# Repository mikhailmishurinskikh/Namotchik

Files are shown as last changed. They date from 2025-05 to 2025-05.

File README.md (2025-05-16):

# Намотчик

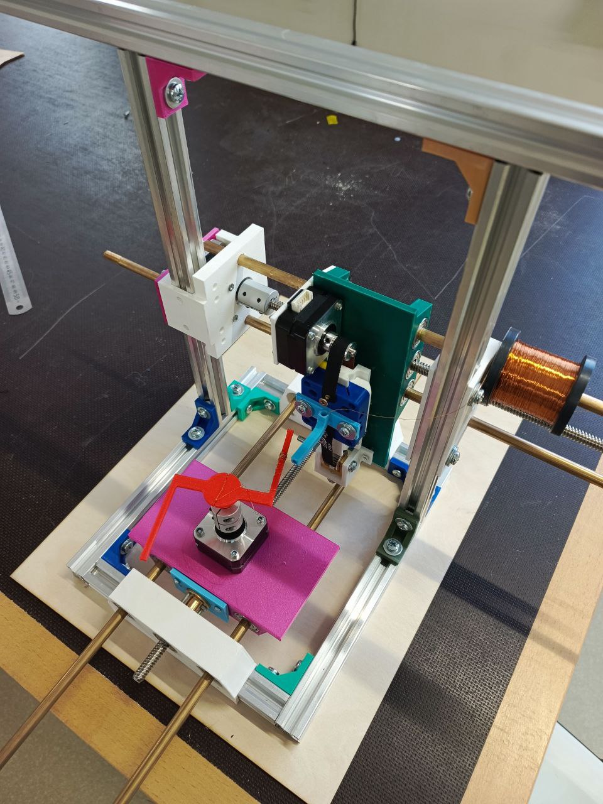
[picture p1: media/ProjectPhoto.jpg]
Фото устройства

Видео демонстрации работы приведено в Видео

## Команда
1. **Мишуринских Михаил**  
   - Email: mishurinskikh.mn@phystech.edu  
   - Telegram: [@mis246](https://t.me/mis246)  
   - Роль: проектирование деталей, сборка  

2. **Новосёлов Ярослав**  
   - Email: novoselov.iav@phystech.edu  
   - Роль: написание управляющей программы, проектирование деталей  

## Причины выбора проекта
Большие возможности для практического применения проекта, его универсальность.

## Достигнутая цель
Создано устройство для автоматической намотки проволоки на звукосниматели и другие объекты

## Задачи
1. Проектирование необходимых деталей: 
   - Угловые соединители алюминиевых профилей
   - Держатели для ходовых винтов
   - Вертикальная и горизонтальная платформы
   - Устройство для натяжения ремня
   - Держатели для двигателей
   - Рельса для вертикального движения прицеливающего устройства
2. Сборка корпуса из напечатанных деталей, алюминиевых профилей
3. Установка платформ, организация их движения при помощи ходового винта
4. Создание коробки для электроники
5. Написание управляющей программы
6. Настройка и тестирование устройства

## Описание устройства
Устройство напоминает по устройству 3D-принтер: оно состоит из прицеливающего устройства, которое способно перемещаться по трём осям над объектом (катушкой или звукоснимателем) и наматывать на него проволоку. 

**Конструкция:**
- Корпус состоит из двух рамок: вертикальной и горизонтальной.
- Над горизонтальной рамкой находится платформа с шаговым двигателем, закрепленная с применением ходового винта (перемещается по горизонтальной оси).
- Вертикальная платформа закреплена на другом ходовом винте и перемещается по оси, перпендикулярной нижней платформе.
- На платформе расположен электродвигатель, перемещающий ремень с кареткой и прицеливающим устройством.
- Для натяжения ремня используется специальное приспособление.

**Принцип работы:**  
Конструкция позволяет прицеливающему устройству вращаться вокруг объекта (закрепленного на двигателе) и наматывать на него проволоку.

## Описание процесса решения задач
1. **Создание корпуса:**
   - Напечатаны держатели для ходового винта (`three`, `three_up` в репозитории).
   - Напечатаны угловые соединители (`angle`), собран корпус из алюминиевых профилей.
2. **Установка платформ:**
   - Напечатаны платформы (`plate`, `plate_up`), держатель для двигателя (`holder`).
   - Установлены на корпус с использованием ходового винта и латунных балок.
3. **Система с ремнем:**
   - Напечатаны рельса (`rail`), каретка (`carriage`), натягивающее устройство (`fixskiv`, `fixfixskiv`).
   - Закреплен ремень, достигнуто перемещение каретки при вращении двигателя.
4. **Электроника:**
   - Создана коробка для электроники.
5. **Программирование:**
   - Написан код для движения каретки (лежит в репозитории).
6. **Тестирование:**
   - Напечатан образец звездочки для намотки.
   - Создана тестовая программа для демонстрации работы.

## Существующие аналоги и альтернативы
1. [Видео с подобной системой перемещения каретки](https://youtu.be/BMVNzjB5hds?si=kCWIetpFhRKtm2jW)
2. [Видео с похожей конструкцией](https://youtu.be/jD39MupZx00?si=GmyoavpNxICr1N5V)
3. [Статья с другим дизайном намотчика](https://3dtoday.ru/blogs/alkutepov/kak-ya-sobiral-namotocnyi-stanok-dlya-namotki-katusek-zvukosnimatelei)

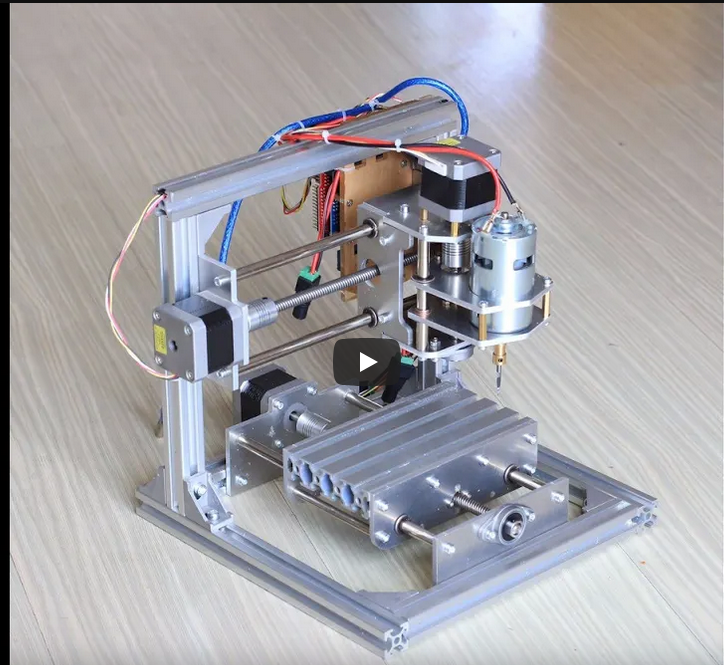
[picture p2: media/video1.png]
Похожая конструкция
  
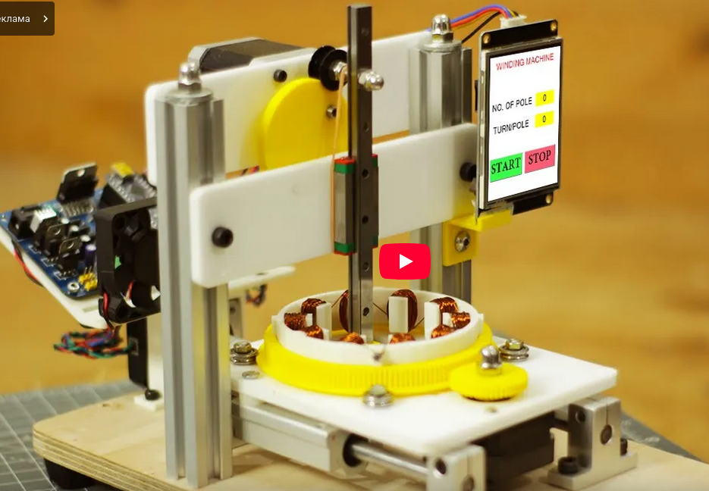
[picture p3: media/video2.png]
Основной аналог
  

### Отличия проекта от аналогов:
- Использование системы с ремнем для вертикального перемещения каретки (высокая скорость).
- Возможность легкого переконструирования под конкретные задачи.
- Намотка с внешней стороны звездочки (в аналогах — с внутренней).

### Недостатки и доработки:
- Требуется подбор параметров намотки.
- Необходима панель управления.
- Улучшение внешнего вида.

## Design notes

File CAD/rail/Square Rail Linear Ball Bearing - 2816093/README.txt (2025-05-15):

Square Rail Linear Ball Bearing by 3DPRINTINGWORLD on Thingiverse: https://www.thingiverse.com/thing:2816093

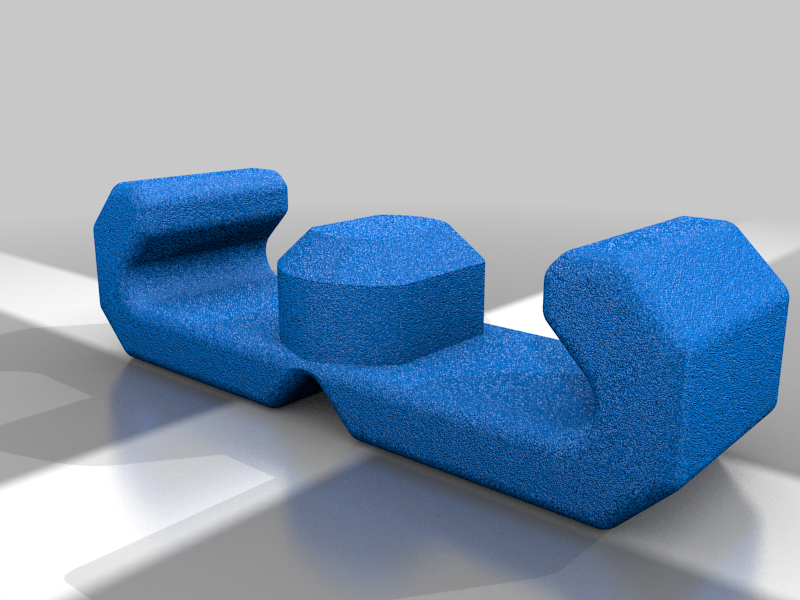
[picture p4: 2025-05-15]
CAD/rail/Square Rail Linear Ball Bearing - 2816093/images/674540b3cc713451a258298c891a3b4f.png

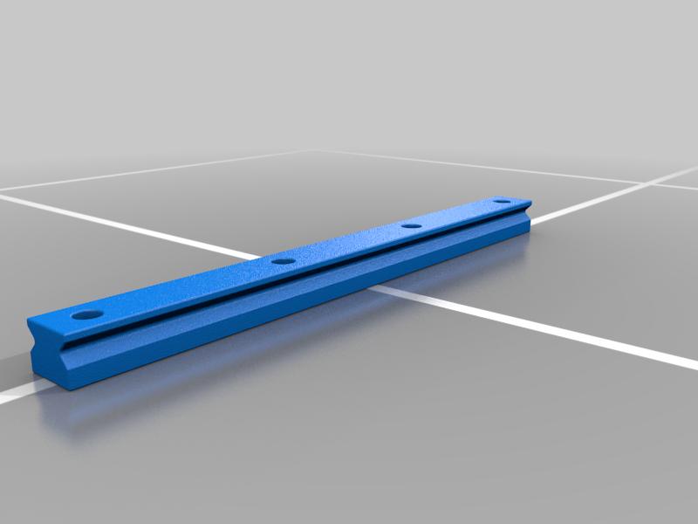
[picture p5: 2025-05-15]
CAD/rail/Square Rail Linear Ball Bearing - 2816093/images/a7a430d8cf4bb123bb5e223ab3fe0eaa.png

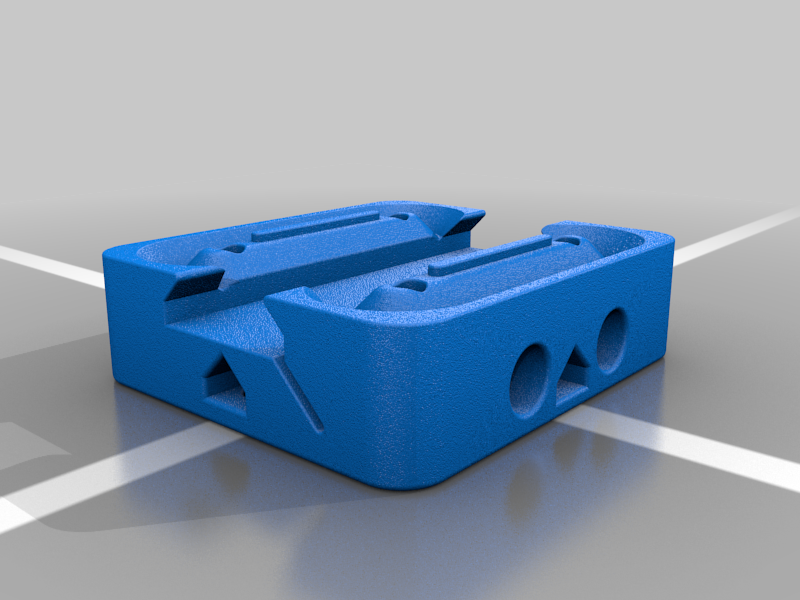
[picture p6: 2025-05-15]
CAD/rail/Square Rail Linear Ball Bearing - 2816093/images/061dc79fe75d56e6988cc07eb85009e7.png

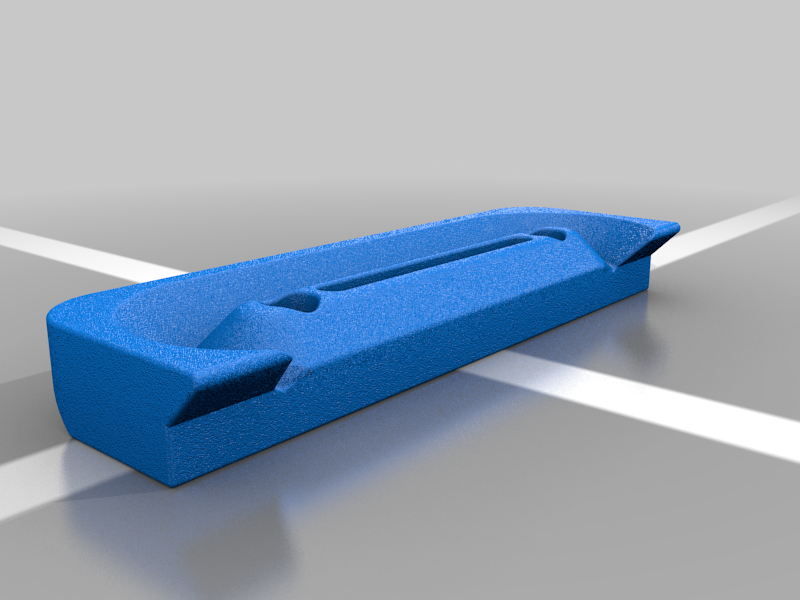
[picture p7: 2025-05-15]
CAD/rail/Square Rail Linear Ball Bearing - 2816093/images/fa1c53716b4c98238ab20a3283d675de.png

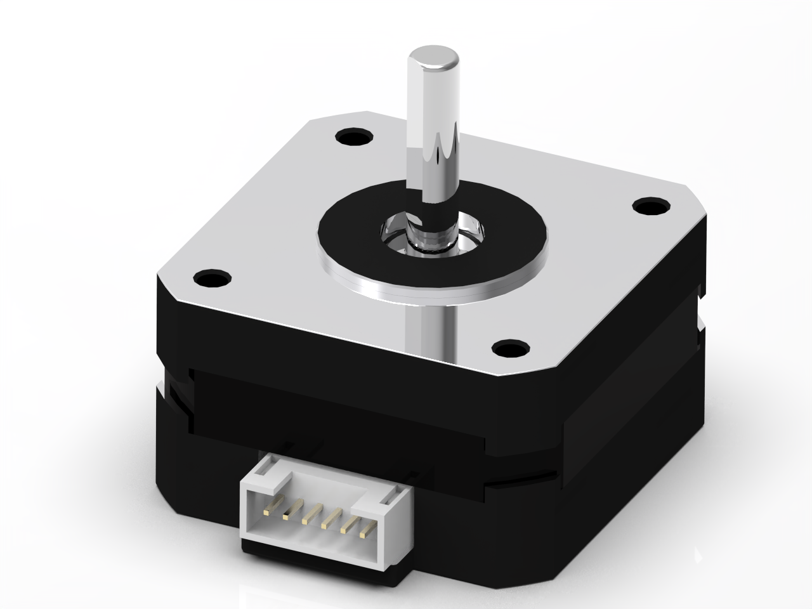
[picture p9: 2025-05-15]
CAD/nemasmall/nema-17-pancake-17hs4023-1.snapshot.6/sdasda.2.png

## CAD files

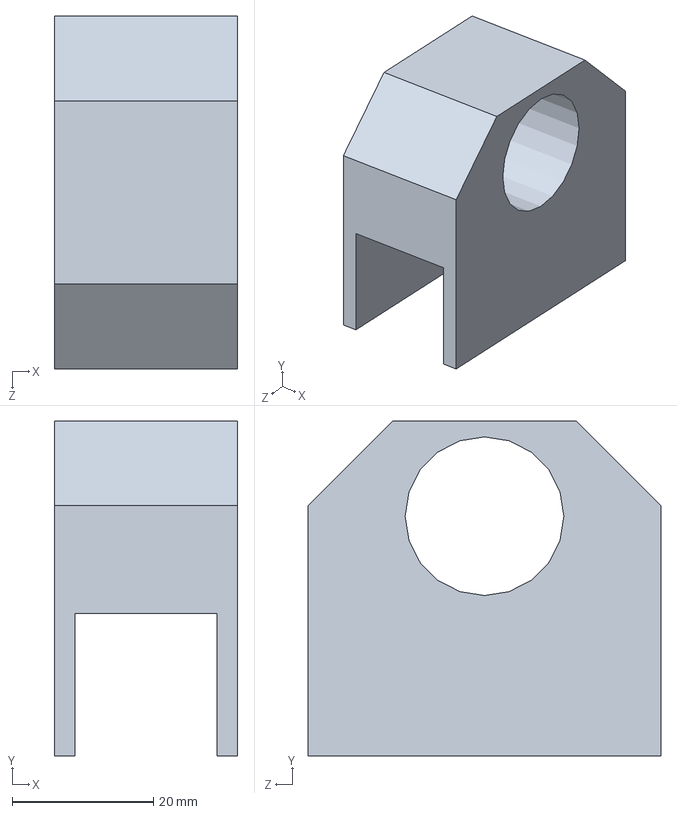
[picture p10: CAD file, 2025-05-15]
CAD/mainBearingDown.SLDPRT
26.0 x 47.5 x 50.0 mm

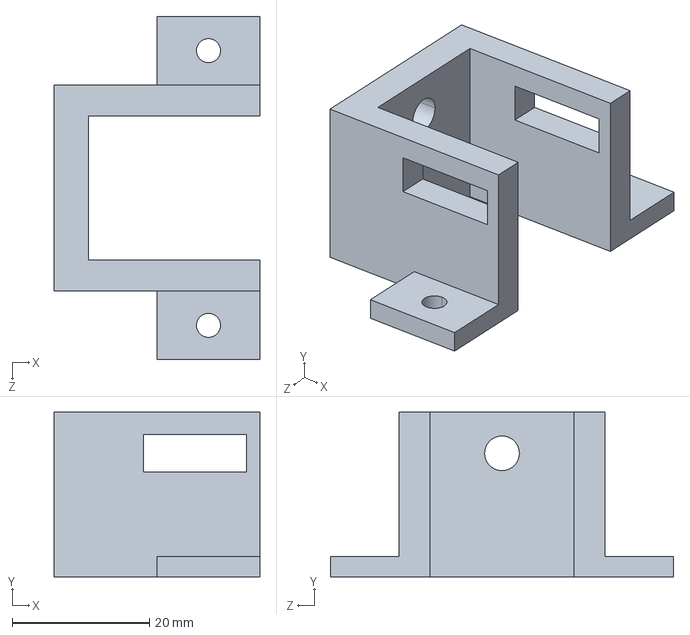
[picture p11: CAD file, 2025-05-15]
CAD/fixfixskiv.STEP
30.0 x 24.0 x 50.0 mm

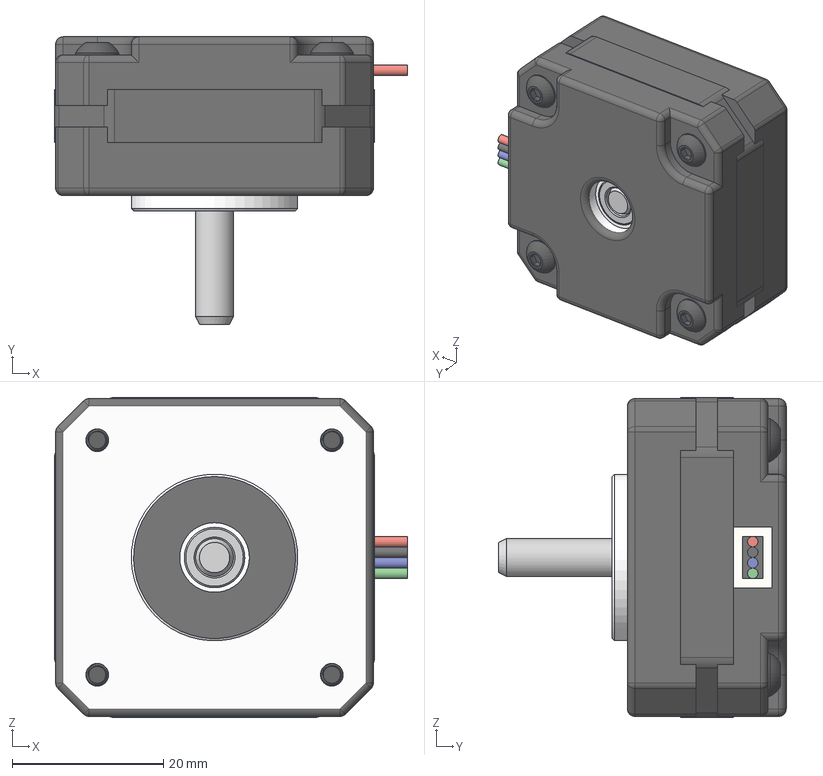
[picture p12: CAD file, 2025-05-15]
CAD/nemasmall/17hm08-1204s-nema17-pancake-21mm-1.snapshot.2/17HM08-1204S Nema17 Pancake 21mm.step
46.7 x 38.0 x 42.3 mm
M3 - 12mm 92095A183 x 4
Front body
Back body
Middle body
Bearings
Shaft
Wire guard
Wires

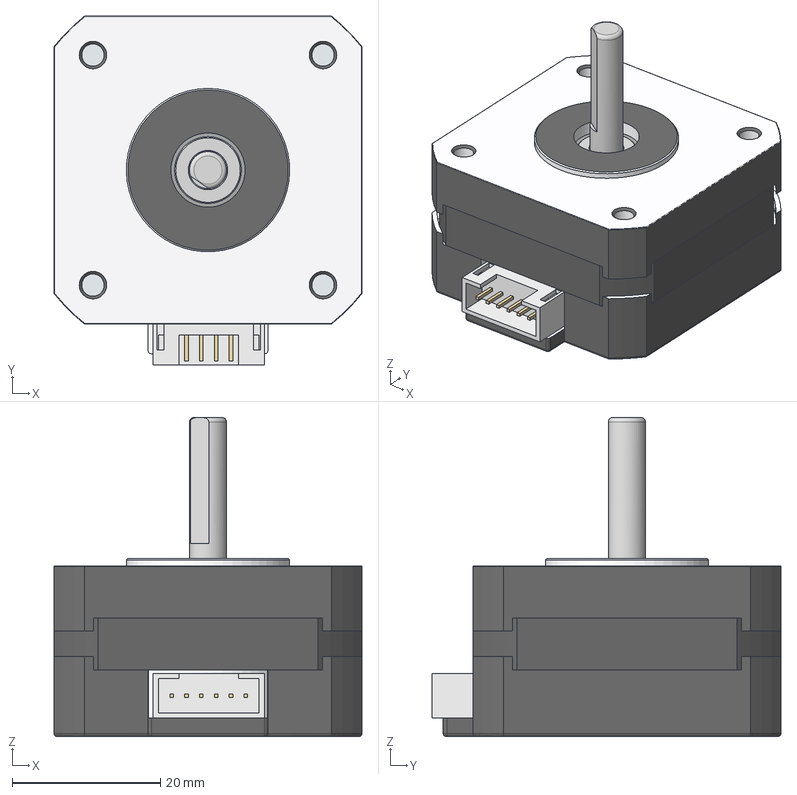
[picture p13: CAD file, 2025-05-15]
CAD/nemasmall/nema-17-pancake-17hs4023-1.snapshot.6/nema17_pancake.stp
41.5 x 47.0 x 43.0 mm
back_plate
front_plate
stator
625ZZ x 2
rotor
connector
M3_screw x 4

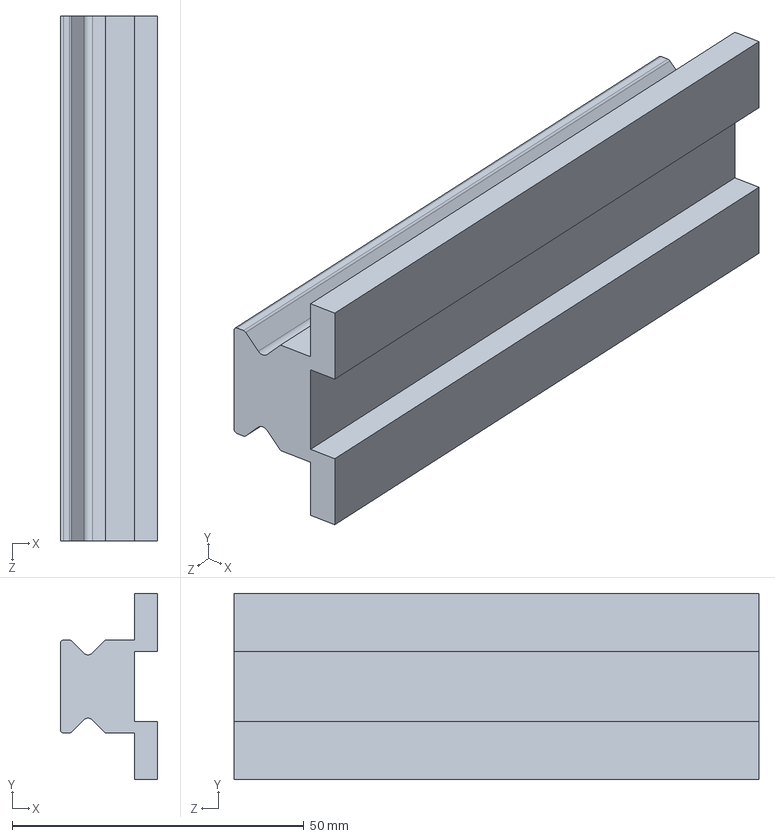
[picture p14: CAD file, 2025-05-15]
CAD/rail/railWORK.SLDPRT
16.7 x 31.9 x 90.0 mm

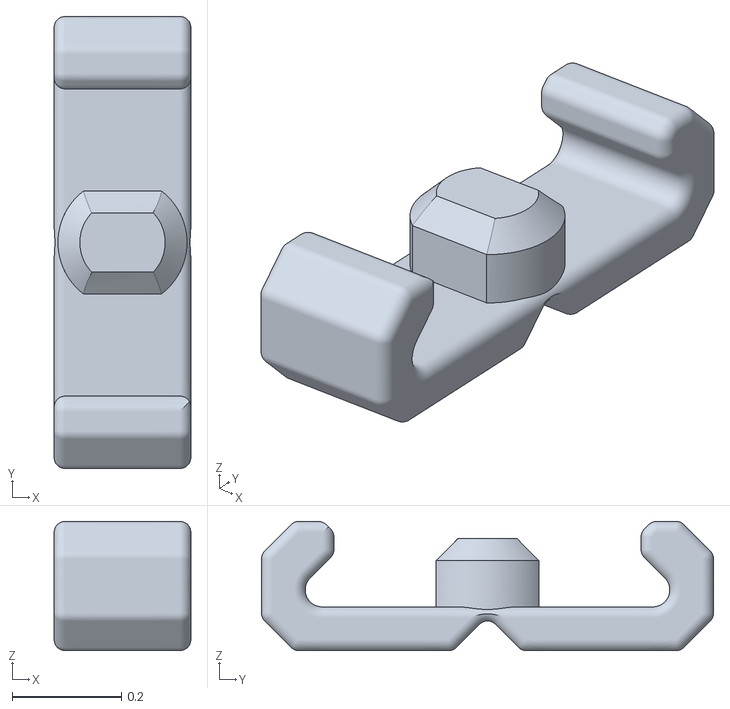
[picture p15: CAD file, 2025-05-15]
CAD/rail/Square Rail Linear Ball Bearing - 2816093/files/LB-V1-RAIL_STOP.stl
0.25 x 0.826 x 0.236

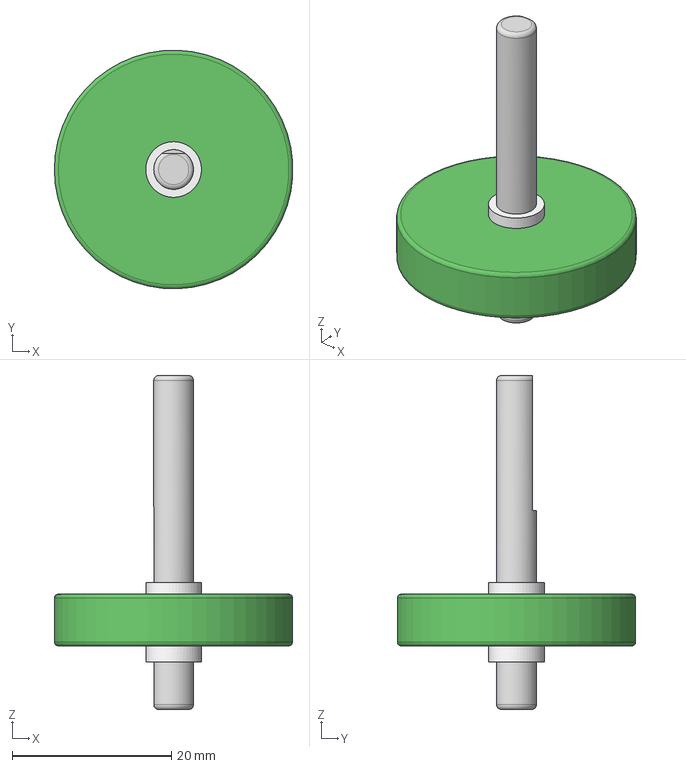
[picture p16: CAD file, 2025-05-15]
CAD/nemasmall/nema-17-pancake-17hs4023-1.snapshot.6/rotor.stp
30.0 x 30.0 x 42.0 mm

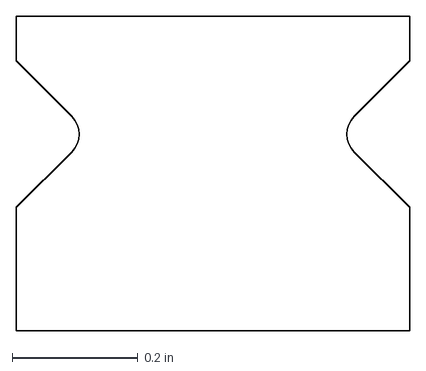
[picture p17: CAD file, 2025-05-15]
CAD/rail/Square Rail Linear Ball Bearing - 2816093/files/SINGLE_RAIL_XSECTION.dxf
0.626 x 0.5 in

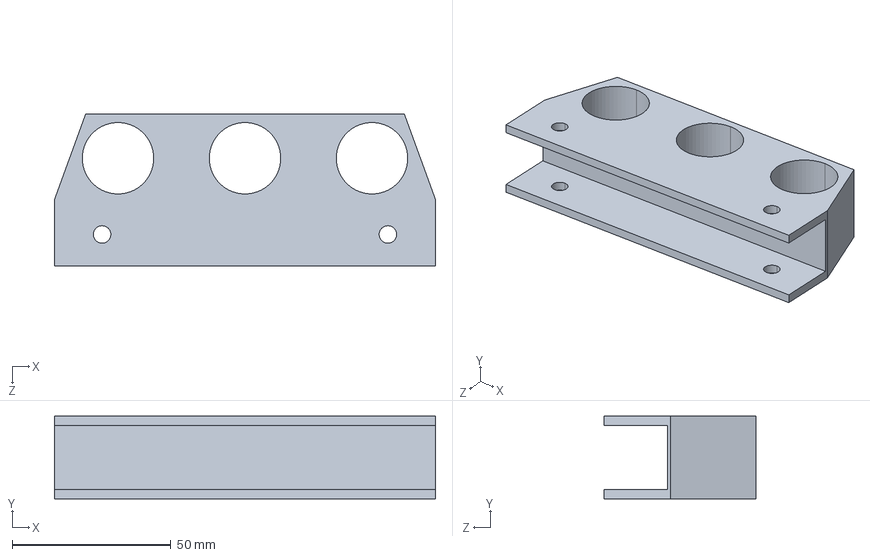
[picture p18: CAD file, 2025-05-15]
CAD/three.STEP
120.0 x 26.0 x 48.0 mm

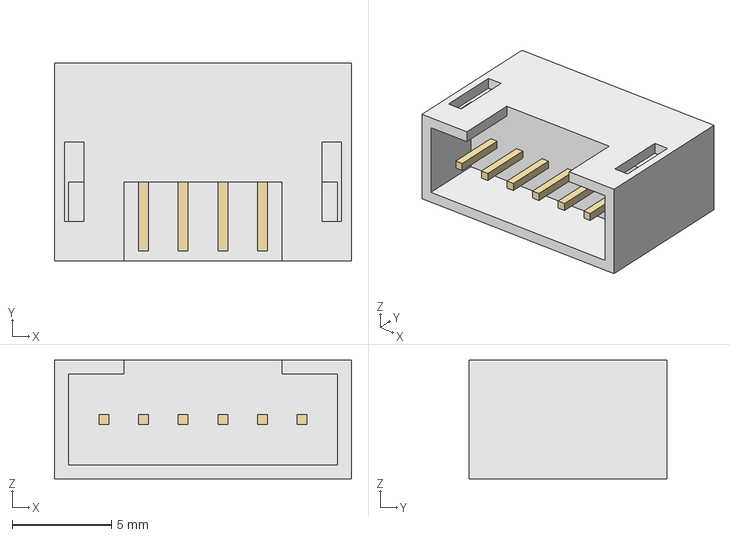
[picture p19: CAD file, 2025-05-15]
CAD/nemasmall/nema-17-pancake-17hs4023-1.snapshot.6/connector.stp
15.0 x 10.0 x 6.00 mm

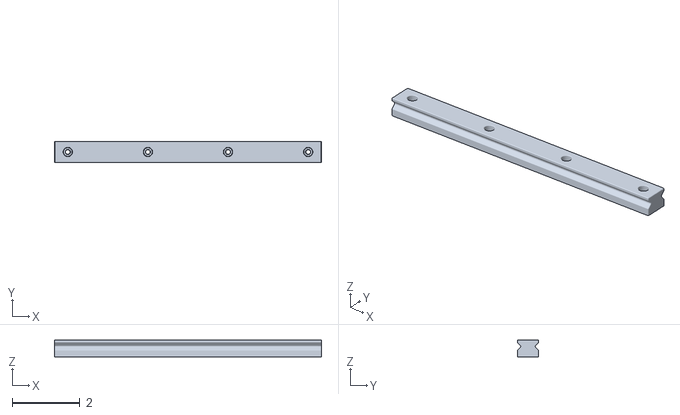
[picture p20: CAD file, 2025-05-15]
CAD/rail/Square Rail Linear Ball Bearing - 2816093/files/LB-V1-RAIL.stl
7.87 x 0.626 x 0.5

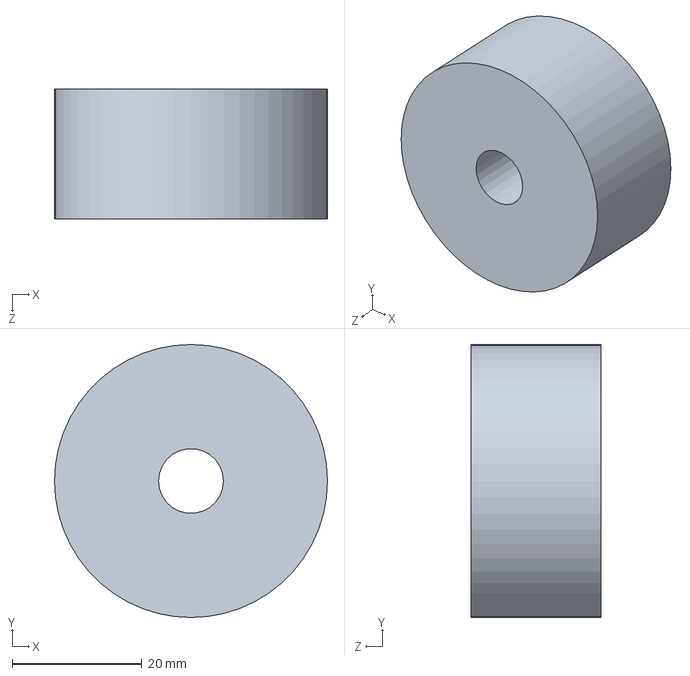
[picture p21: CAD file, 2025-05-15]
CAD/shkiv2.SLDPRT
42.1 x 42.1 x 20.1 mm

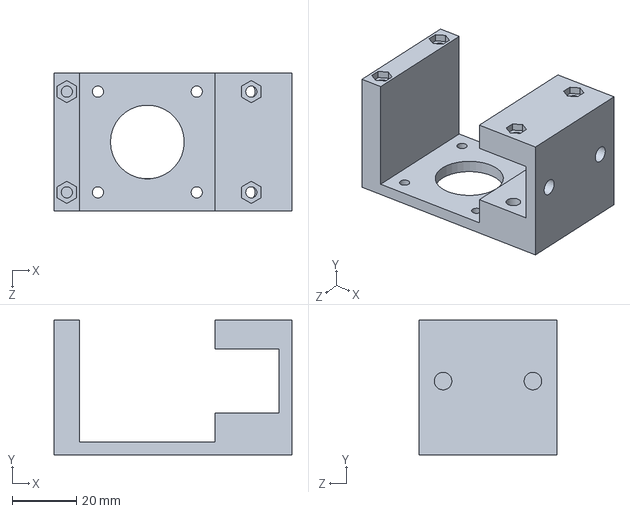
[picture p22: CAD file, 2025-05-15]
CAD/holder-1.SLDPRT
74.2 x 42.0 x 43.0 mm

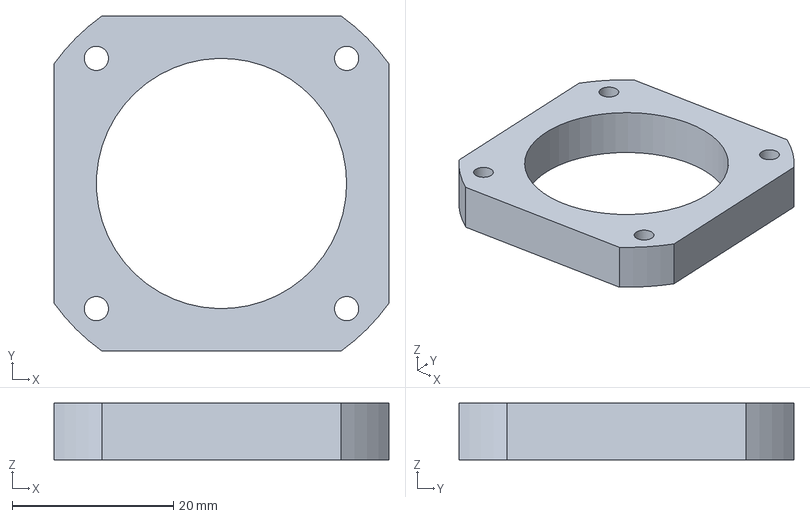
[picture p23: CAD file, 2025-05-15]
CAD/nemasmall/nema-17-pancake-17hs4023-1.snapshot.6/stator.stp
41.5 x 41.5 x 7.00 mm

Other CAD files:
CAD/load.SLDASM
CAD/rail/Square Rail Linear Ball Bearing - 2816093/files/LB-V1-BEARING_COVER.stl
CAD/nemasmall/nema-17-pancake-17hs4023-1.snapshot.6/625ZZ.stp
CAD/plateUp.STEP
CAD/Bearing.SLDPRT
CAD/DownLong.SLDPRT
CAD/DownShort.SLDPRT
CAD/Move_holder.SLDPRT
CAD/Move_holder.STEP
CAD/Part1.SLDPRT
CAD/RailDown.SLDPRT
CAD/UpLong.SLDPRT
CAD/beltbear.SLDPRT
CAD/fixfixskiv.SLDPRT
CAD/fixskiv.SLDPRT
CAD/fixskiv.STEP
CAD/holder-2.SLDPRT
CAD/holder.SLDPRT
CAD/holder.STEP
CAD/nemasmall/nema-17-pancake-17hs4023-1.snapshot.6/M3_screw.stp
CAD/nemasmall/nema-17-pancake-17hs4023-1.snapshot.6/back_plate.stp
CAD/nemasmall/nema-17-pancake-17hs4023-1.snapshot.6/front_plate.stp
CAD/new_holder.STEP
CAD/pipe.SLDPRT
CAD/pipe.STEP
CAD/plastina.SLDPRT
CAD/plastina.STEP
CAD/plate.SLDPRT
CAD/plate.STEP
CAD/plateUp.SLDPRT
CAD/railWORK.STEP
CAD/shkiv.SLDPRT
CAD/shkivNATYAZ.SLDPRT
CAD/star.SLDPRT
CAD/star.STEP
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
